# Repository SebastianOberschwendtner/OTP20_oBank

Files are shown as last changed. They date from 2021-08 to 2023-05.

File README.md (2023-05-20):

Card
# OTP-20_oBank







Open Source Power Bank with Power Delivery Capability.

>More information can be found in the *beautiful* [wiki](https://github.com/SebastianOberschwendtner/OTP20_oBank/wiki/home).

>:construction: The **schematic** and **PCB** are designed with *CircuitMaker*. The project can be found [here](https://circuitmaker.com/Projects/Details/SebastianOberschwendtner/OTP-20oBank).

## Software Framework
<!-- ![IDE1](https://img.shields.io/static/v1?label=IDE&message=Eclipse&color=yellowgreen) -->







## Branches
|Name|Status|Description|
|---|---|---|
|**Main**|`active`| Main branch for developing with VSCode|
 
## Technical Data
|Type|Value|
|---|---|
|*Microcontroller*| **STM32L071**|
|*Battery*| **Li-Ion 18650 7.4V 5000 mAh**|
|*Charger IC*|**BQ25700**|
|*Fuel Gauge IC*| **MAX17205**|
|*PD Controller IC*|**TPS65987**|

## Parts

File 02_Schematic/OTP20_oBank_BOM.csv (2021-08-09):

Designator | Comment | Description | Quantity | Footprint Name | Order from | Manufacturer | Manufacturer Part Number
C1, C2, C24 | 470 nF | Capacitor, MLCC, 0805 | 3 | 0805 | Reichelt
C3, C29, C38, C40, C41, C42, C43, C53, C59, C60, C61, C77 | 100 nF | Capacitor, MLCC, 0805 | 12 | 0805 | Reichelt
C4, C5 | 1 nF | Capacitor, MLCC, 0805 | 2 | 0805 | Reichelt
C6, C7, C8, C10, C11, C12, C13, C14, C15, C16, C17, C18, C28, C47, C48, C50, C51, C52, C55, C56, C57, C58, C64, C65, C66, C67 | 10 uF | Capacitor, MLCC, 0805 | 26 | 0805 | Reichelt
C9 | 47 uF | Capacitor; Alum Electrolytic; Cap 47 uF; Tol 20%; Vol-Rtg 50 VDC; SMT; 6.3x5.8; CT | 1 | 6.3x5.8 | Reichelt
C19, C73, C74, C75, C76, C79, C80 | 10 nF | Capacitor, MLCC, 0805 | 7 | 0805 | Reichelt
C20, C21 | 47 nF | Capacitor, MLCC, 0805 | 2 | 0805 | Reichelt
C22, C23 | 15 nF | Capacitor, MLCC, 0805 | 2 | 0805 | Reichelt
C25, C26 | 150 pF | Capacitor, MLCC, 0805 | 2 | 0805 | Reichelt
C27, C30 | 1 uF | Capacitor, MLCC, 0805 | 2 | 0805 | Reichelt
C31 | 33 pF | Capacitor, MLCC, 0805 | 1 | 0805 | Reichelt
C32 | 680 pF | Capacitor, MLCC, 0805 | 1 | 0805 | Reichelt
C33, C69 | 2.2 uF | Capacitor, MLCC, 0805 | 2 | 0805 | Reichelt
C34 | 1.8 nF | Capacitor, MLCC, 0805 | 1 | 0805 | Reichelt
C35 | 15 pF | Capacitor, MLCC, 0805 | 1 | 0805 | Reichelt
C36 | 100 pF | Capacitor, MLCC, 0805 | 1 | 0805 | Reichelt
C37 | 22 pF | Capacitor, MLCC, 0805 | 1 | 0805 | Reichelt
C39, C46, C62, C68, C70, C72, C78 | 1.0 uF | Capacitor, MLCC, 0805 | 7 | 0805 | Reichelt
C44, C45 | 220 pF | Capacitor, MLCC, 0805 | 2 | 0805 | Reichelt
C49, C71 | 4.7 uF | Capacitor, MLCC, 0805 | 2 | 0805 | Reichelt
C54, C63 | 10 pF | Capacitor, MLCC, 0805 | 2 | 0805 | Reichelt
K1 | Molex 22-05-7065 | 2.50mm Pitch SPOX Wire-to-Board Header, Right Angle, Shrouded, Friction Lock, 6 Circuits | 1 |  | Reichelt
K5 | Molex 22-03-5045 | Headers & Wire Housings 2.5 VERT HDR SPOX 4P shrouded | 1 |  | Reichelt |  | 22-03-5045
LED1 | Würth Elektronik 150060GS75000 | Led, Green, 520 Nm, 3.2 V, 30 Ma, 430 Mcd Rohs Compliant: Yes | 1 | 0603 | Reichelt |  | 150060GS75000
LED2 | Würth Elektronik 150060RS75000 | Led, Red, 2.0 V, 30 Ma, 430 Mcd Rohs Compliant: Yes | 1 | 0603 | Reichelt |  | 150060S75000
Q6, Q7 | International Rectifier IRLML2502TRPBF | Single N-Channel 20 V 1.25 W 8 nC Hexfet Power Mosfet Surface Mount - MICRO-3 | 2 | SOT-23 | Reichelt |  | IRLML2502TRPBF
R1, R2 | 3.3 kO | RESISTOR, 0805 | 2 | 0805 | Reichelt
R3, R5 | 20.0 O | Thick Film Resistors - SMD 1206 20ohms 1% Tolerance | 2 | 1206 | Reichelt |  | ERJ-8ENF20R0V
R4, R19, R32, R39, R40 | 10 kO | RESISTOR, 0805 | 5 | 0805 | Reichelt
R6, R7 | 200.0 O | Thick Film Resistors - SMD 1206 200ohms 1% Tolerance | 2 | 1206 | Reichelt |  | ERJ-8ENF2000V
R10, R11, R14, R15, R17, R24 | 10 O | RESISTOR, 0805 | 6 | 0805 | Reichelt
R12 | 1.0 O | RESISTOR, 0805 | 1 | 0805 | Reichelt
R16 | 270 kO | RESISTOR, 0805 | 1 | 0805 | Reichelt
R18 | 390 kO | RESISTOR, 0805 | 1 | 0805 | Reichelt
R20 | 40.2 kO | RESISTOR, 0805 | 1 | 0805 | Reichelt
R21 | 137 kO | RESISTOR, 0805 | 1 | 0805 | Reichelt
R22 | 120 kO | RESISTOR, 0805 | 1 | 0805 | Reichelt
R23, R27, R33, R41 | 100 kO | RESISTOR, 0805 | 4 | 0805 | Reichelt
R25 | 68 O | RESISTOR, 0805 | 1 | 0805 | Reichelt
R26 | 1.00 kO | Surface Mount Thin Film Resistor, AEC-Q200 ERA Series, 1 kohm, 125 mW, - 0.1%, 100 V | 1 | 0805 | Reichelt |  | ERA6AEB102V
R28, R29, R35, R36, R37, R38 | 100 O | RESISTOR, 0805 | 6 | 0805 | Reichelt
R30, R42, R43, R45, R46, R47, R48, R55, R56 | 0.0 O | RESISTOR, 0805 | 9 | 0805 | Reichelt
R31 | 1 kO | RESISTOR, 0805 | 1 | 0805 | Reichelt
R34 | 2.2 O | Thick Film Resistors - SMD 0805 2.2ohms 1% Tol | 1 | 0805 | Reichelt
R44 | 16 kO | RESISTOR, 0805 | 1 | 0805 | Reichelt
R49, R51 | 124 kO | RESISTOR, 0805 | 2 | 0805 | Reichelt
R50, R52 | 22.1 kO | RESISTOR, 0805 | 2 | 0805 | Reichelt
R53 | 110 kO | RESISTOR, 0805 | 1 | 0805 | Reichelt
R54 | 360 kO | RESISTOR, 0805 | 1 | 0805 | Reichelt
R57 | 2.2 O | RESISTOR, 0805 | 1 | 0805 | Reichelt
K2 | 632723300011 | USB 3.1 Type C Receptacle WR-COM, Horizontal, SMT / THT, PCB thickness 1.6mm | 1 |  | Mouser | Würth | 632723300011
K3, K4 | USB-A | Conn Rcpt USB2.0 Typea 4POS R/a | 2 |  | Mouser |  | 614004160211
L1 | 2.2 uH | SMD Power Inductor WE-LHMI, L=2.2 uH | 1 | 1040 | Mouser | Wuerth | 74437368022
L2, L3 | 3.3 uH | Surface Mount Power Inductor, We-Lhmi Series, 3.3 H, 20%, Shielded, 0.038 Ohm, 4.1 A Rohs Compliant: Yes | 2 | 5030 | Mouser |  | 74437336033
Q1, Q2, Q3, Q4 | Texas Instruments CSD17551Q3A | Trans MOSFET N-CH 30V 48A 8-Pin VSONP EP T/R | 4 |  | Mouser |  | CSD17551Q3A
Q5 | Texas Instruments CSD25402Q3A | MOSFET Transistor, P Channel, -35 A, -20 V, 0.0077 ohm, -4.5 V, 900 mV | 1 |  | Mouser |  | CSD25402Q3A
R8 | 5 mO | Res Metal Strip 0612 0.005 Ohm 1% 1W ±150ppm/C Wide Terminal SMD Automotive T/R | 1 |  | Mouser
R9, R13 | 10 mO | Res 0.01 Ohm 1% 1W 1206 | 2 |  | Mouser |  | CRK0612-FZ-R010E
SW1 | Würth Elektronik 434331045822 | Tact Switch 3.5x4.7mm Black Side push | 1 |  | Mouser |  | 434331045822
U1 | MAX17205G+ | Stand-Alone Model Gauge m5 Fuel Gauge with SHA-256 Authentication | 1 | QFN | Mouser |  | MAX17205G+
U2 | BQ25700ARSNR | NVDC SMBus Battery Buck-Boost Charge Controller with System Power Monitor & Processor 32-QFN -40 to 85 | 1 |  | Mouser |  | BQ25700ARSNR
U3 | STM32L071KZU6 | MCU 32-Bit Ultra Low Power STM32L ARM Cortex M0+ RISC 192kB Flash 32-Pin UFQFPN Tray | 1 | QFN | Mouser |  | STM32L071KZU6
U4 | TPS65987DDHRSHT | USB Type-C and USB PD Controller With Integrated Power Switches 56-VQFN -40 to 85 | 1 | QFN | Mouser |  | TPS65987DDHRSHT
U5 | TPS54295PWPR | Conv DC-DC 4.5V to 18V Synchronous Step Down Dual-Out 0.76V to 7V 2A/2A 16-Pin HTSSOP EP T/R | 1 | TSSOP | Mouser |  | TPS54295PWPR
U6 | LDL212DR | Low Dropout Regulators(LDO) Positive Adjustable 600mV @ 1.2A 18V 1.18V 1.2A SOIC-8_150mil RoHS | 1 | SOIC | Mouser |  | LDL212DR
U7 | LDF33DT | Fixed Ldo Voltage Regulator, 2.6V To 16V, 200Mv Dropout, 3.3Vout, 1Aout, To-252-3 Rohs Compliant: Yes | 1 | TO-252 | Mouser |  | LDF33DT
U8 | TPD6S300RUKR | USB Type-C port protector: short-to-VBUS overvoltage and 6-ch ESD protection 20-WQFN -40 to 85 | 1 | QFN | Mouser |  | TPD6S300RUKR

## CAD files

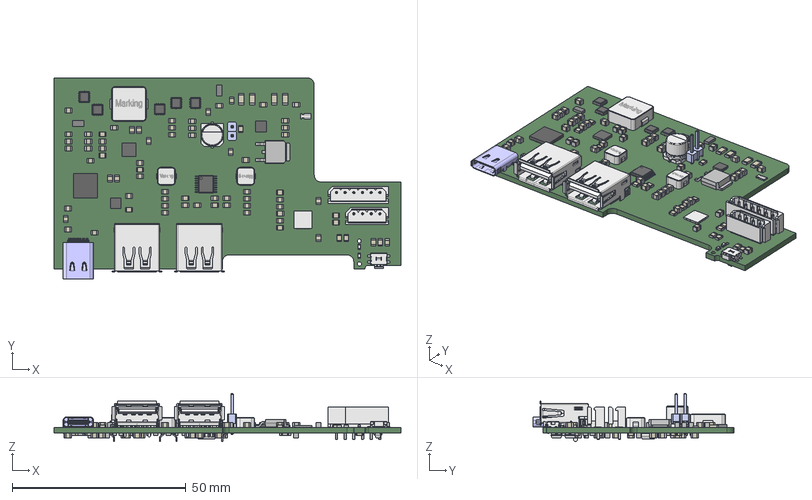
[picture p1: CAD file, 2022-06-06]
04_Hardware/30_PCB/Main_PCB.FCStd
100.0 x 58.0 x 13.8 mm
Extruded
Extruded001
Extruded002
Extruded003
Extruded004
Extruded005
Extruded006
Extruded007
Extruded008
Extruded009
Extruded010
Extruded011
Extruded012
Extruded013
Extruded014
Extruded015
Extruded016
Extruded017
Extruded018
Extruded019
Extruded020
Extruded021
Extruded022
Extruded023
Extruded024
Extruded025
Extruded026
Extruded027
Extruded028
Extruded029
Extruded030
Extruded031
Extruded032
Extruded033
Extruded034
Extruded035
Extruded036
Extruded037
Extruded038
Extruded039
Extruded040
Extruded041
Extruded042
Extruded043
Extruded044
Extruded045
Extruded046
Extruded047
Extruded048
Extruded049
Extruded050
Extruded051
Extruded052
Extruded053
Extruded054
Extruded055
Extruded056
Extruded057
Extruded058
Extruded059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

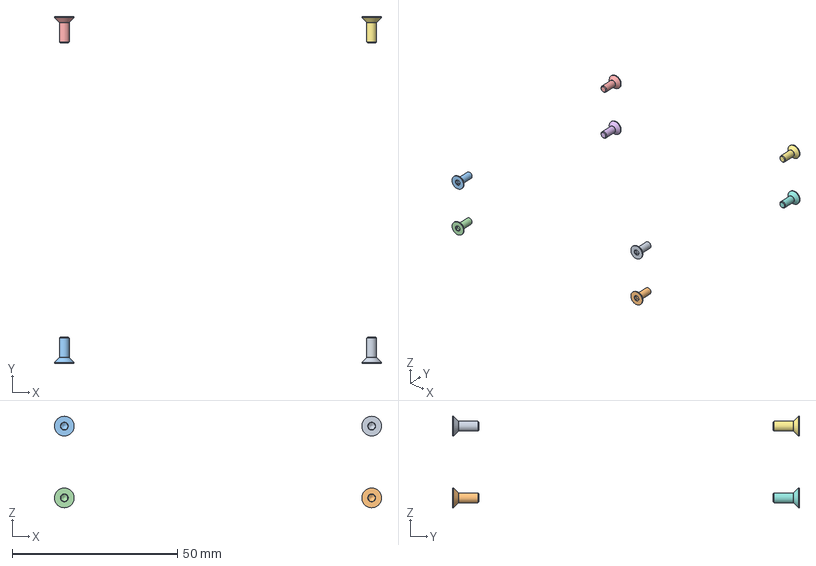
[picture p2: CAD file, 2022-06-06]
04_Hardware/10_Case/OTP20_Case_Assembly.FCStd
99.0 x 105.0 x 27.7 mm
M3x8-Screw x 2
M3x8-Screw089 x 2
M3x8-Screw090 x 2
M3x8-Screw091 x 2
M3x8-Screw108 x 2
M3x8-Screw109 x 2
M3x8-Screw110 x 2
M3x8-Screw111 x 2

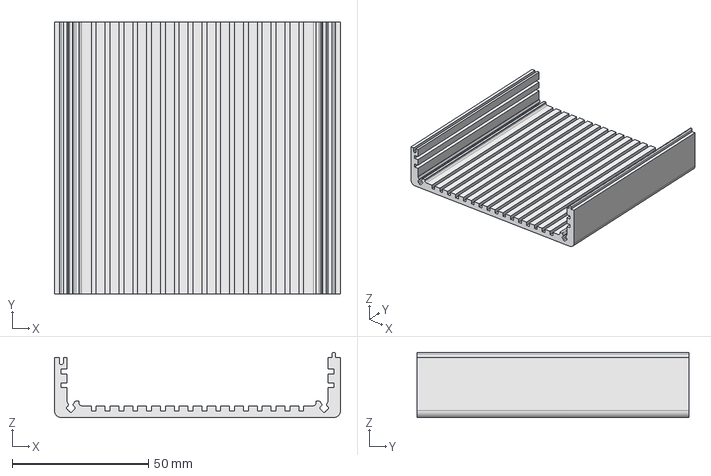
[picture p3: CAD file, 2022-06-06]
04_Hardware/10_Case/KOH-2100.FCStd
105.0 x 100.0 x 23.9 mm
Slice.0 x 2

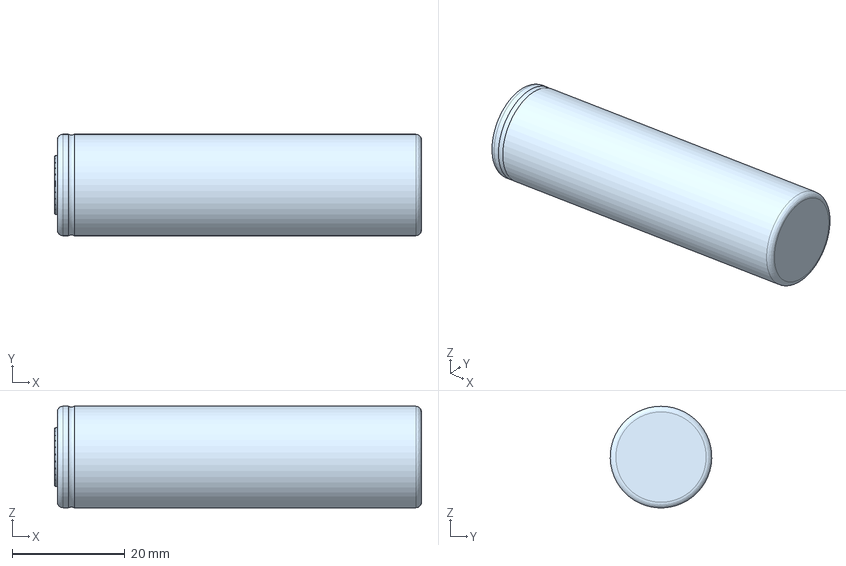
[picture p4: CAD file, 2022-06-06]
04_Hardware/20_COTS/LiIon_18650.FCStd
65.0 x 18.0 x 18.0 mm

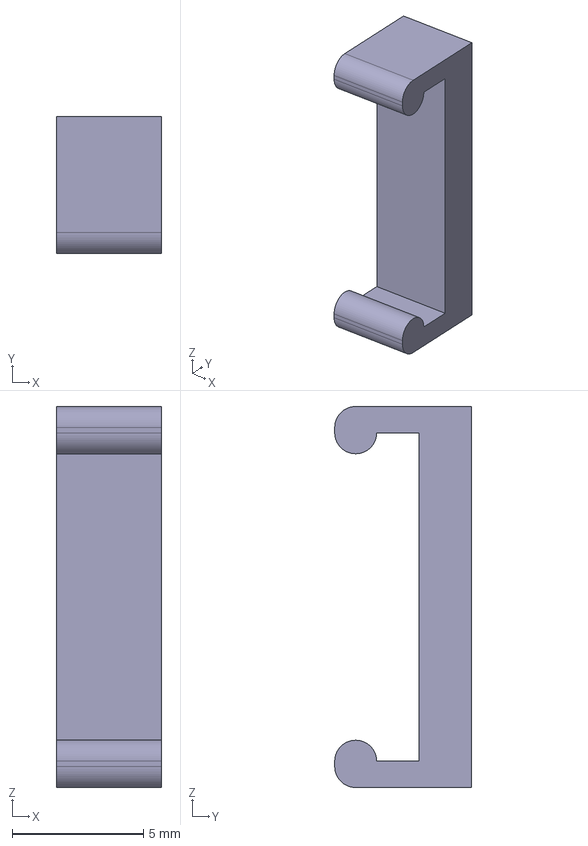
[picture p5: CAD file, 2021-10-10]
04_Hardware/40_Parts/OTP20_Display_Bracket.FCStd
4.00 x 5.20 x 14.5 mm

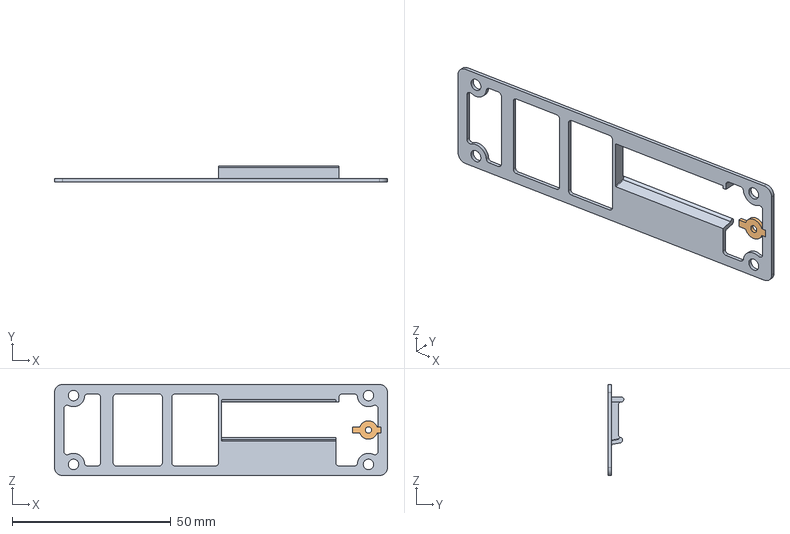
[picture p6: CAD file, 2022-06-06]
04_Hardware/10_Case/OTP20_Case_Bezel.FCStd
105.0 x 4.90 x 28.7 mm
Inner Frame
Button

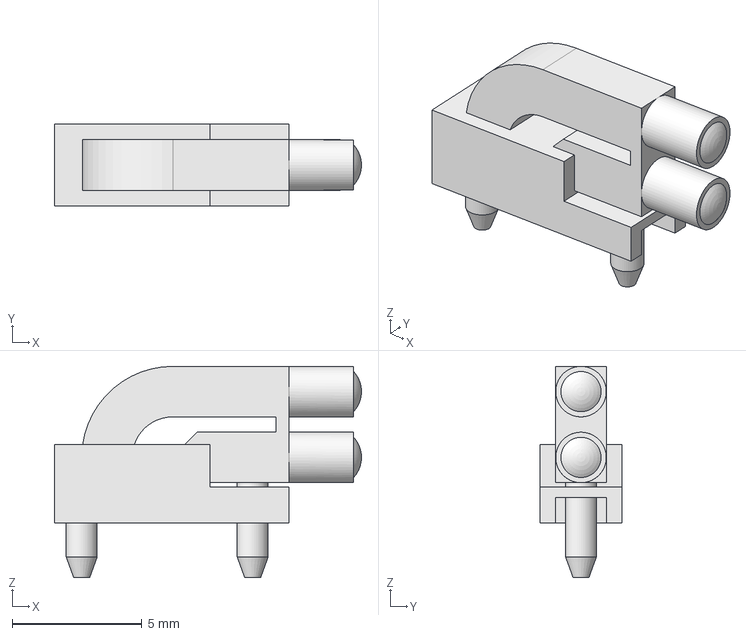
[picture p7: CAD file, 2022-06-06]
04_Hardware/20_COTS/Lightpipe_Mentor_1296-2012.FCStd
11.9 x 3.16 x 8.16 mm

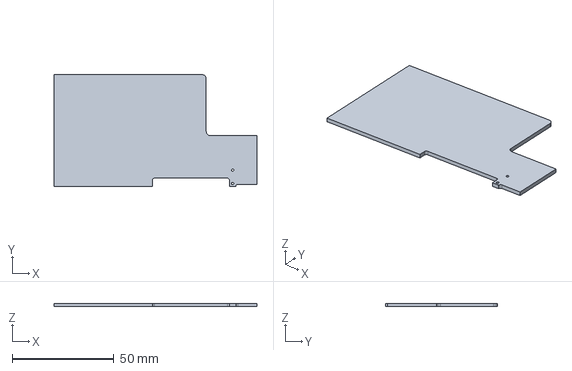
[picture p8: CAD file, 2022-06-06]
04_Hardware/30_PCB/PCB_Outline.FCStd
100.0 x 55.0 x 1.70 mm

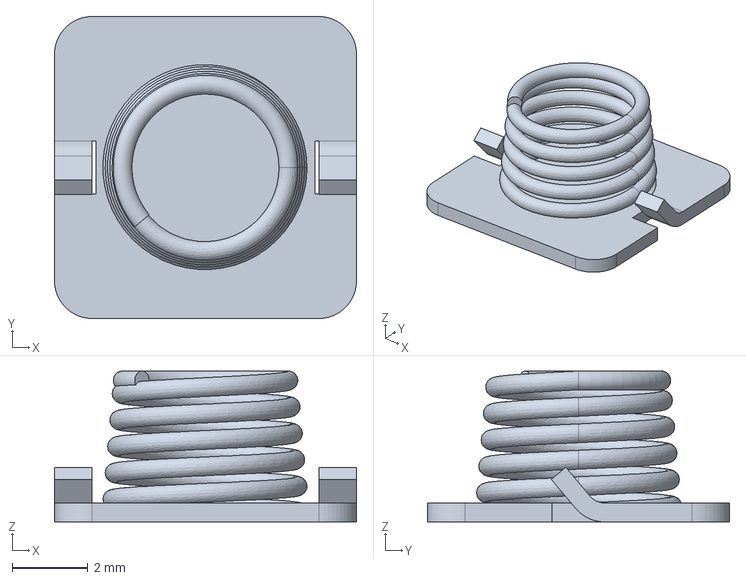
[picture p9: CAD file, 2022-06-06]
04_Hardware/20_COTS/Battery_Contact_Spring.FCStd
8.00 x 8.00 x 4.00 mm

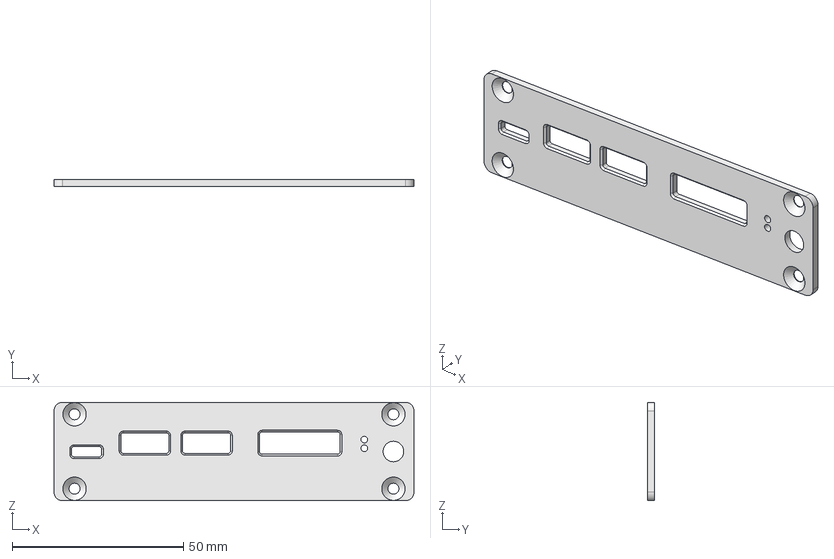
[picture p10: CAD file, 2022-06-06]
04_Hardware/10_Case/KOH_Plate_Front.FCStd
105.0 x 2.00 x 28.7 mm

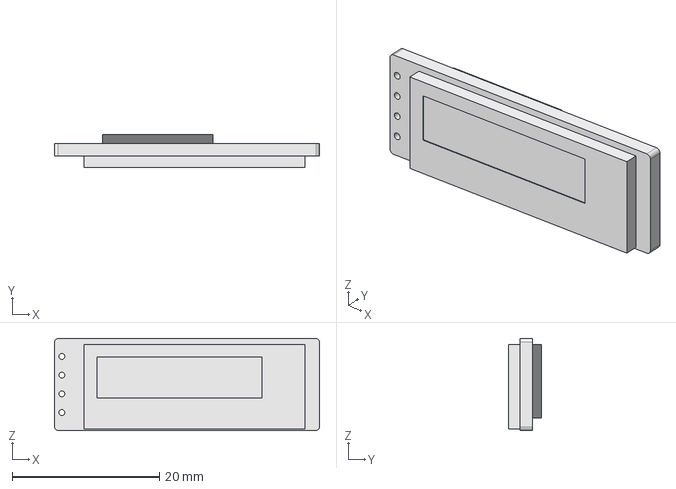
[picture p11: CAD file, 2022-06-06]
04_Hardware/20_COTS/Waveshare_OLED_0.91in.FCStd
36.0 x 4.50 x 12.5 mm
Mainboard
Components

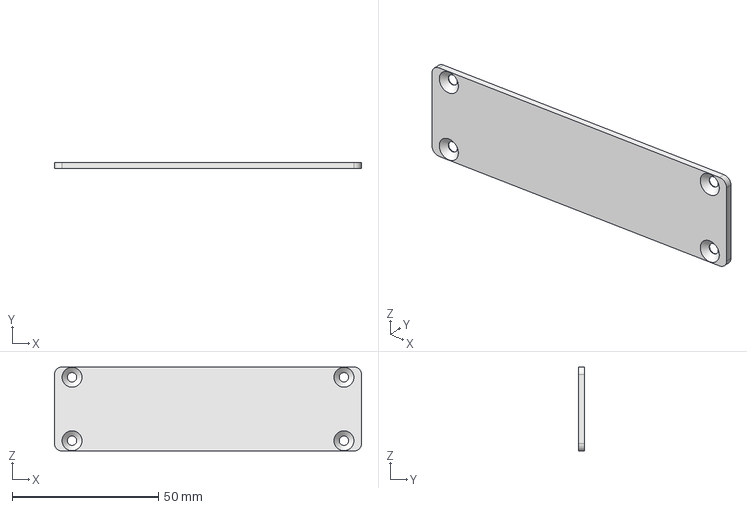
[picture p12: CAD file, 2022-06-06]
04_Hardware/10_Case/KOH_Plate_Back.FCStd
105.0 x 2.00 x 28.7 mm

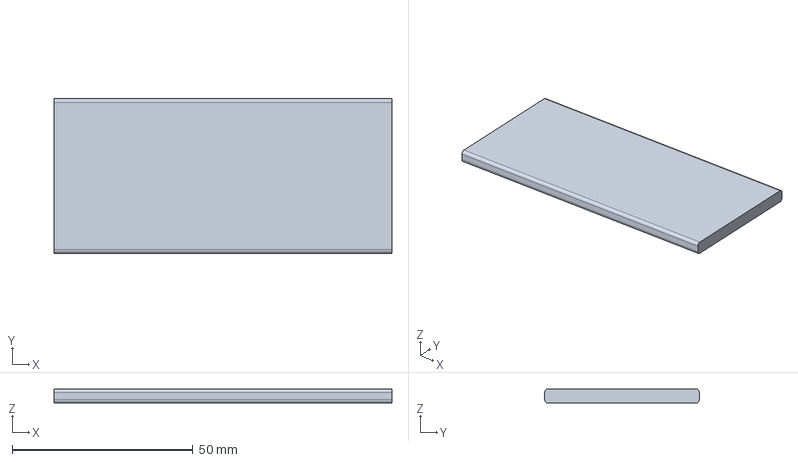
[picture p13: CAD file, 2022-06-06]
04_Hardware/20_COTS/Battery_Pouch.FCStd
93.4 x 42.7 x 4.00 mm

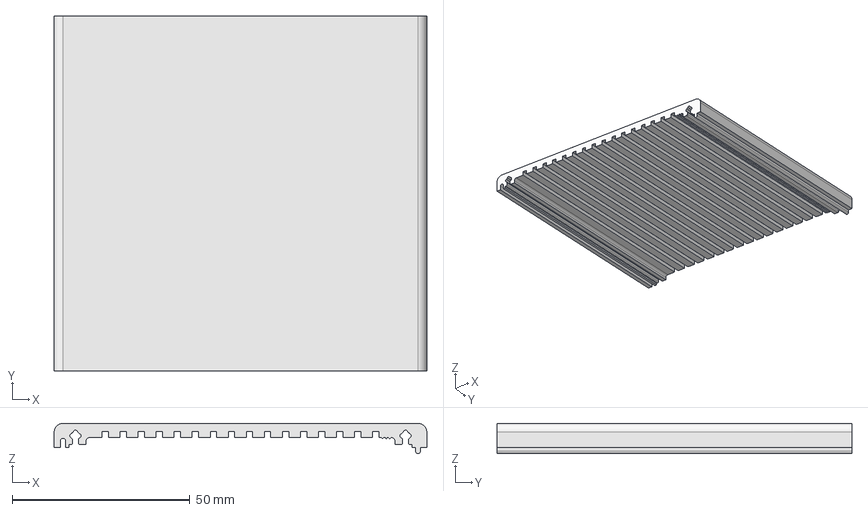
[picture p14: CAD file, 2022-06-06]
04_Hardware/10_Case/KOH-0100.FCStd
105.0 x 100.0 x 8.53 mm

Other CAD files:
04_Hardware/OTP20_Assembly.FCStd
04_Hardware/30_PCB/OTP20_PCB_Assembly.FCStd
04_Hardware/20_COTS/USB_C_Connector_Wuerth.FCStd
04_Hardware/20_COTS/Battery_Contact_Flat.FCStd
04_Hardware/20_COTS/EA_W064048.FCStd
04_Hardware/20_COTS/Lightpipe_Mentor_1271-1001.FCStd
04_Hardware/20_COTS/Lightpipe_Mentor_1282-2000.FCStd
04_Hardware/20_COTS/USB_A_Connector_Wuerth.FCStd

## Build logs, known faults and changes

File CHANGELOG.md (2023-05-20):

# Changelog for OTP-20 oBank
## [v4.0.0](https://github.com/SebastianOberschwendtner/OTP20_oBank/releases/tag/v4.0.0) *(2023-xx-xx)*

>Released by `SO`

### Release Notes:
#### :bookmark: `v3.1.0`
- Major update of IPC messaging within the tasks.
- Activates the *ALRT* pin of the BMS chip to prevent battery damage. Fixes #7.
- Led indicate the actual output state not just the assumed one.

### Fixed Issues:

- #6: Cell balancing not working *(Not a direct software issue)*
- #7: Add automatic shutoff when battery is depleted

## [v3.0.0](https://github.com/SebastianOberschwendtner/OTP20_oBank/releases/tag/v3.0.0) *(2023-05-07)*

>Released by `SO`

### Release Notes:
#### :bookmark: `v2.1.0`
- Adds **ETL** state machine to system task.
- Adds **ETL** state machine to display task.
- Adds further BMS parameters to the GUI.
#### :bookmark: `v3.0.0`
- Activates the PD controller.
- Refactors the interprocess communication and adds command queues using **ETL**.

### Fixed Issues:

- n/a

## [v2.0.0](https://github.com/SebastianOberschwendtner/OTP20_oBank/releases/tag/v2.0.0) *(2022-06-06)*

>Released by `SO`

### Release Notes:
- Update OTOS version to `v2.7.4`

### Fixed Issues:

- n/a

## [v1.0.0](https://github.com/SebastianOberschwendtner/OTP20_oBank/releases/tag/v1.0.0) *(2021-10-10)*

>Released by `SO`

### Release Notes:
- Initial release of *oBank*.

> This is more or less a pre-release to get started with the releases.

### Fixed Issues:

- n/a

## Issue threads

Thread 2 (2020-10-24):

Gerber Release

SebastianOberschwendtner, 2020-10-24:
**Describe the solution you'd like**
Release the gerber files of the board once they are finsihed.

**Additional context**
The board is designed with *CircuitMaker* and the raw files cannot be included in this repo.

Closed 2022-06-06.

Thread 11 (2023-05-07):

Enable when outputs during charging

SebastianOberschwendtner, 2023-05-07:
# Current Behavior
Actually a bit unclear what happens when you enable the outputs while the power bank is charging.

# Expected Behavior
It would be nice to still use the two USB-A ports when the power bank is charging. So the power
adapter can be used to charge the battery and the connected devices.

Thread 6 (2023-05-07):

Cell balancing not working

SebastianOberschwendtner, 2023-05-07:
# Current Behavior
The cell balancing seems not to work although it should be enabled.

# Expected Behavior
The cell balancing should work reliably.

SebastianOberschwendtner, 2023-05-20:
# Update
As it turns out the balancing is actually active, but has a very **limited** window of operation, which is actually explained in the data sheet.
The balancing only starts when the *SoC* is above approx. 95% and stops when the discharge current gets to high.
There are additional conditions to be met, see datasheet.

In theory, the chip keeps balancing when the power bank is in sleep mode, but when the BMS chip is in hipernate mode the balancing is very slow.
Maybe after an initial balancing of the pack this is sufficient for normal use. &rArr; This will be investigated during use.

SebastianOberschwendtner, 2023-08-19:
# Update
After some use, it looks like the balancing is working just fine. It is a bit slow for the size of the battery, but it does its job in the end.

&rArr; I will close this issue now.

Closed 2023-08-19.

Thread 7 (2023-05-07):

Add automatic shutoff when battery is depleted

SebastianOberschwendtner, 2023-05-07:
# Current Behavior
The output can be enabled at all SoCs of the battery. The power bank does not check whether all cell are good.

# Expected Behavior
The power bank should always monitor the battery state and prevent the battery from being damaged.
This includes:
- [ ] Undervoltage checks
- [ ] Cell voltage difference check
- [ ] Cell temperature checks

Closed 2023-05-20.

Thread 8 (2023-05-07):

Separate output power modes

SebastianOberschwendtner, 2023-05-07:
**Is your feature request related to a problem? Please describe.**
When only using one output of the power bank it seems wasteful to have all the outputs enabled.
Also it would be nice to not always output the full power on USB-C port, when you want your phone to be charged slowly.

**Describe the solution you'd like**
Have different power modes which can be enabled.

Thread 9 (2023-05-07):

Rework USB PD GUI page

SebastianOberschwendtner, 2023-05-07:
# How it should look like
The USB PD page of the GUI should give information about the current contract and whether the output is active or not.
Also it should look nice.

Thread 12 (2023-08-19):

Latest gccarmnoneeabi toolchain breaks ETL state chart

SebastianOberschwendtner, 2023-08-19:
**Describe the bug**
When compiling with the latest *gccarmnoneeabi* tool chain, the *ETL* state chart seems to break.

**Additional context**
When using an older version of the gcc tool chain, everything seems to work again.
- ✔️ Working: `1.100301.220327`
- :x: Not working: `1.120201.221222`

**Tasks**
- [ ] Find out what the changes in between the tool chain versions are.
- [ ] Fix the bug.

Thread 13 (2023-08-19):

Add proper configuration of MAX17205

SebastianOberschwendtner, 2023-08-19:
**Is your feature request related to a problem? Please describe.**
Whenever you change a single **BMS** parameter the *MAX17205* configuration does not get updated, because of the limited write cycles the firmware does not upgrade its configuration every time.
However, the current configuration values are not written to non-volatile memory anyway, so writing it on every reset should not be damaging. :thinking_face:

**Describe the solution you'd like**
The configuration of the *MAX17205* should get updated reliably.

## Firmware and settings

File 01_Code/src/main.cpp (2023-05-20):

/**
 * OTP20 - oBank
 * Copyright (c) 2021 Sebastian Oberschwendtner, sebastian.oberschwendtner@gmail.com
 *
 *
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
 */
/**
 ******************************************************************************
 * @file    main.cpp
 * @author  SO
 * @version v3.1.0
 * @date    14-September-2021
 * @brief   Main firmware for the oBank.
 ******************************************************************************
 */

// === Includes ===
#include "main.h"

// === Functions ===
OTOS::Kernel OS; // NOLINT

// === Main ===
int main() // NOLINT
{
    // Configure the SysTick timer to generate an interrupt every 1ms
    Timer::SysTick_Configure();

    // Schedule Threads
    OS.schedule_thread<512>(&Task_System , OTOS::Priority::High, 5);
    OS.schedule_thread<512>(&Task_Display, OTOS::Priority::Normal);
    OS.schedule_thread<512>(&Task_PD     , OTOS::Priority::Normal);
    OS.schedule_thread<512>(&Task_BMS    , OTOS::Priority::Normal);

    // Start the task execution
    OS.start();

    // Never reached
    return 0;
};

/** 
 * @brief Provide a Interrupt handler for the systick timer,
 * which gets called every 1 ms.
 */
extern "C" void SysTick_Handler(void)
{
    OS.update_schedule();
    OS.count_time_ms(); // NOLINT
};

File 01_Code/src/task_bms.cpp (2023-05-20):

/**
 * OTP20 - oBank
 * Copyright (c) 2021 Sebastian Oberschwendtner, sebastian.oberschwendtner@gmail.com
 *
 *
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
 */
/**
 ******************************************************************************
 * @file    task_bms.cpp
 * @author  SO
 * @version v3.1.0
 * @date    09-October-2021
 * @brief   Task for the Battery Management of the oBank
 ******************************************************************************
 */

// === Includes ===
#include "task_bms.h"
#include "drivers.h"
#include "task.h"
#include "configuration.h"

namespace {
    // === Global data within task ===
    // *** I/O pins ***
    GPIO::PIN CHR_OK(GPIO::Port::A, 2, GPIO::Mode::Input);
    GPIO::PIN ALRT1(GPIO::Port::A, 3, GPIO::Mode::Input);
    GPIO::PIN EN_OTG(GPIO::Port::B, 5, GPIO::Mode::Output);
    GPIO::PIN EN_5V{GPIO::Port::B, 6, GPIO::Mode::Output};
    GPIO::PIN SCL(GPIO::Port::A, 9);
    GPIO::PIN SDA(GPIO::Port::A, 10);
    // *** i2c controller ***
    I2C::Controller i2c(IO::I2C_1, 100000);
    // *** Charger controller ***
    BQ25700::Controller Charger(i2c);
    // *** BMS chip ***
    MAX17205::Controller Battery(i2c);
    // *** IPC Mananger ***
    IPC::Manager ipc_manager(IPC::Check::PID<IPC::BMS>());
    // *** IPC Interface ***
    IPC::BMS_Interface ipc_interface;
    IPC::PD_Interface *pd_interface;

    // === Functions ===
    /**
     * @brief Initialize the BMS task.
     */
    void initialize()
    {
        // Disable all outputs
        EN_OTG.set_state(false);
        EN_5V.set_state(false);

        // Setup the IPC interface
        ipc_manager.register_data(&ipc_interface);
        pd_interface = IPC::wait_for_data<IPC::PD_Interface>(IPC::PD);

        // Set up the i2c interface
        SCL.set_alternate_function(IO::I2C_1);
        SDA.set_alternate_function(IO::I2C_1);
        i2c.enable();

        // Initialize the charger interface
        CHR_OK.set_pull(GPIO::Pull::Pull_Up);
        CHR_OK.enable_interrupt(GPIO::Edge::Both);
        Charger.initialize();
        Charger.set_OTG_voltage(5000);
        Charger.set_OTG_current(2000);
        BQ25700::ChargeOption0 option0;
        Charger.read(option0);
        if (! option0.EN_OOA() )
        {
            option0.set_EN_OOA(true); // Enable Out-of-Audio mode
            Charger.write(option0);
        }

        // Initialize the BMS Chip
        ALRT1.set_pull(GPIO::Pull::Pull_Up);
        ALRT1.enable_interrupt(GPIO::Edge::Both);
        Battery.initialize();
        MAX17205::PackCfg config;
        MAX17205::Config alert;
        MAX17205::SAlrtTh thresholds;
        Battery.read(config);
        Battery.read(alert);
        Battery.read(thresholds);
        if (! config.ChEn() ) // When this flag is not set, it is assumed the chip is not initialized
        {
            // Set the cell configuration
            config.value = (MAX17205::TdEn | MAX17205::ChEn | MAX17205::BALCFG_1 | MAX17205::BALCFG_0 | 2U);
            Battery.write(config);

            // Set the alert thresholds
            thresholds.set_SMIN(User::Power::SoC_minimum);
            thresholds.set_SMAX(0xFF); // Disable max SOC alert
            Battery.write(thresholds);

            // Enable the alerts
            alert.set_ALRTp(false); // ALRT1 pin is active low
            alert.set_Aen(true); // Enable the alerts
            Battery.write(alert);
        }

        OTOS::Task::yield();
    }
}; // namespace

/**
 * @brief Main task for handling the BMS
 */
void Task_BMS()
{
    // Setup stuff
    initialize();

    // Setup the message router
    BMS::Handler handler(IPC::PID::BMS); // NOLINT

    // Start looping
    while(true)
    {
        // Handle the command queue
        while(not ipc_interface.command_queue.empty())
        {
            handler.receive(ipc_interface.command_queue.front().get());
            ipc_interface.command_queue.pop();
        }

        // Read battery data
        Battery.read_battery_current_avg();
        Battery.read_battery_voltage();
        Battery.read_cell_voltage();
        Battery.read_remaining_capacity();
        Battery.read_soc();
        Battery.read_TTE();
        Battery.read_TTF();

        // Manage charging
        if (CHR_OK.get_state())
        {
            // EN_OTG.set_low();
            // Charger.enable_OTG(false);
            // Input power is present, set charge current
            Charger.set_charge_current(User::Power::Max_Charge_Current);
        }
        else if ( not ALRT1.get_state())
        {
            // battery reports some alert -> disable all outputs
            EN_5V.set_low();
            EN_OTG.set_low();
            Charger.enable_OTG(false);
        }

        OTOS::Task::yield();
    };
}

extern "C" void EXTI2_3_IRQHandler(void)
{
    CHR_OK.reset_pending_interrupt();
    ALRT1.reset_pending_interrupt();
}

// === IPC interface ===

/**
 * @brief Set everything up for sleepmode
 */
void IPC::BMS_Interface::sleep()
{
    // Disable the pullup to save power
    // CHR_OK.set_pull(GPIO::Pull::No_Pull);
}

/**
 * @brief Set everything up after waking up
 */
void IPC::BMS_Interface::wake()
{
    // Enable the pullup to sense whether an input is present
    // CHR_OK.set_pull(GPIO::Pull::Pull_Up);
}

/**
 * @brief Get the latest voltage measurement of the battery
 * @return The battery voltage in [mV]
 */
auto IPC::BMS_Interface::get_battery_voltage() -> uint16_t
{
    return ::Battery.get_battery_voltage().get();
}

/**
 * @brief Get the latest current measurement of the battery
 * @return The battery current in [mA]
 */
auto IPC::BMS_Interface::get_battery_current() -> int16_t
{
    return ::Battery.get_battery_current().get();
}

/**
 * @brief Get the latest cell voltage measurement of the battery.
 * @param cell The cell number to get the voltage for (1 or 2).
 * @return The battery current in [mA]
 */
auto IPC::BMS_Interface::get_cell_voltage(unsigned char cell) -> uint16_t
{
    return ::Battery.get_cell_voltage(cell).get();
}

/**
 * @brief Get the remaining battery capacity as reported by the BMS chip.
 * 
 * @return The remaining battery capacity in [mAh]
 */
auto IPC::BMS_Interface::get_remaining_capacity() -> uint16_t
{
    return ::Battery.get_remaining_capacity().get();
}

/**
 * @brief Get the SOC as reported by the BMS chip.
 * 
 * @return The SOC in 0.1[%].
 */
auto IPC::BMS_Interface::get_soc() -> uint16_t
{
    return ::Battery.get_SOC().get();
}

/**
 * @brief Get the estimated time to empty as reported by the BMS chip.
 * 
 * @return  The time to empty in [s].
 */
auto IPC::BMS_Interface::get_time2empty() -> uint32_t
{
    return ::Battery.get_TTE().get();
}

/**
 * @brief Get the estimated time to full as reported by the BMS chip.
 * 
 * @return  The time to full in [s].
 */
auto IPC::BMS_Interface::get_time2full() -> uint32_t
{
    return ::Battery.get_TTF().get();
}
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

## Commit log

2020-10-24 :memo: Added CircuitMaker projekt.
2020-10-27 :nut_and_bolt: Added stl for bezel.
    [OTP20_Bezel_v001.stl]
2020-12-19 :wrench: Adjusted file.
    [OTP20_Bezel_v001.stl]
2021-06-14 :art: Adds first hardware created with FreeCAD.
    [KOH_Plate_Front.FCStd, OTP20_Case_Assembly.FCStd, OTP20_Case_Bezel.FCStd]
2021-06-27 :wrench: Adds KiCad temp files.
2021-06-27 :art: Adds first KiCad files.
    [BMS.sch, BMS_Balancer.sch, BMS_Charger.sch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]
2021-07-01 :x: Reverts the commit of KiCad files.
    This reverts commit 0003e735c34a18542f6e4cef3e63da02411a332b.
    After the brandnew release of CircuitMaker and its bugfixes, this
    project will continue to use CircuitMaker. Well done Altium...
2021-07-01 Revert ":art: Adds first KiCad files."
    This reverts commit da62ad51e9228d03cb72b9540d6a56f4d06397b0.
    [BMS.sch, BMS_Balancer.sch, BMS_Charger.sch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]
2021-07-01 :nut_and_bolt: Adds first components for case assembly.
    [EA_W064048.FCStd, KOH-0100.FCStd, KOH-2100.FCStd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]
2021-07-01 :x: Deletes old folder structure.
    [KOH_Plate_Front.FCStd, OTP20_Case_Assembly.FCStd, OTP20_Case_Bezel.FCStd]
2021-08-09 :tada: REVA Release of schematics.
    [OTP20_oBank_BOM.csv]
2021-08-09 :wrench: Removes additional row in BOM csv file.
    [OTP20_oBank_BOM.csv]
2021-09-16 :art: Adds gerber files.
    [Main_PCB.GBL, Main_PCB.GBO, Main_PCB.GBP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]
2021-09-16 :memo: Updates schematics.
2021-09-17 :art: Adds driver for the battery charger.
2021-09-21 :tada: First pre-release with all drivers working.
2021-09-21 :art: Adds reading of avg current.
2021-09-21 :art: Adds function to read avg cell voltage.
2021-10-10 :nut_and_bolt: Adds battery contacts.
    [Battery_Contact_Flat.FCStd, Battery_Contact_Spring.FCStd]
2021-10-10 :nut_and_bolt: Adds all FreeCAD files.
    [KOH-0100.FCStd, KOH-2100.FCStd, KOH_Plate_Back.FCStd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]
2022-06-06 :racehorse: Updates the firmware to use the newest OTOS release.
    [configuration.h]
2022-06-06 :nut_and_bolt: Updates case assembly.
    [Battery_Contact_Flat.FCStd, Battery_Contact_Spring.FCStd, Battery_Pouch.FCStd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]
2022-06-06 :wrench: Removes STL files.
    Since the FreeCAD files are included in the repo, the newest version of
    the STL files can always be extracted from that.
    [OTP20_Bezel_v001.stl]
2022-06-08 :mag: Cleans up the task and IPC includes.
    [configuration.h]
2022-06-18 :racehorse: Adds ETL state chart to task system.
    [configuration.h]
2022-06-18 :racehorse: Adds ETL state chart to display task.
    [configuration.h]
2022-06-19 :tada: Adds more BMS parameters to GUI.
2023-05-07 :tada: Adds USB PD and refactors IPC.
    [configuration.h]
2023-05-20 :racehorse: Major IPC refactoring, activates ALRT pin. Fixes #7.
    [configuration.h]

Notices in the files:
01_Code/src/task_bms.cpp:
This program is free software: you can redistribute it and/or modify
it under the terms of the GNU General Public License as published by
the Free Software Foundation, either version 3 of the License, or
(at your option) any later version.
